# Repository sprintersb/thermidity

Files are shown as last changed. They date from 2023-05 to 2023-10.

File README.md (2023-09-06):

# Thermidity



AVR MCU based battery powered thermometer and hygrometer with e-ink display.  
Focus is on stable, accurate measurements and low power consumption. 
And of course on a nice, simple display.

The project is based on [avrink](https://github.com/gitdode/avrink) and uses the
following components:

* MCU AVR ATmega328P
* Thermistor NTC 100kΩ 0.1°C
* Humidity Sensor HIH-5030
* E-Ink display Adafruit Monochrome 2.13" 250x122
    * Driver SSD1680
    * SRAM 23K640
    * SD Card Reader (not used)
 
Thanks to https://github.com/sprintersb for helping me to improve the code and making it more efficient!



## Accuracy

AD conversion is done with 16x oversampling, yielding 12-bit virtual resolution 
with the 10-bit ADC, provided the signal contains some noise.

Each time measurements were taken, a moving average is updated which is used to 
calculate and display temperature, humidity and battery voltage.

A precision thermistor and precision low-voltage humidity sensor are used:

| Component  | Accuracy |
|---|---:|
| Thermistor |  ¹±0.1°C |
| HIH-5030 | ±3%RH |

¹Series resistor 0.1% tolerance

## Power Consumption

Estimated average power consumption is about 90µA when measuring every 32 
seconds and updating the display once in about 5 minutes, hopefully giving an
operating time of at least 12 months with 3 AAA batteries (1100 mAh, 6% 
self-discharge). 

The consumption of each component at 3.8V and 22°C is about:

| Component  | Data Sheet | Measured |
|---|---:|---:|
| ATmega328P | ¹4.2µA | 4.5µA |
| Thermistor | N/A | 24µA |
| HIH-5030 | ²200µA | 211µA |
| V-Divider  | N/A | 2µA |
| Display | ³N/A | 14µA |

¹VCC = 3V, power-down sleep mode  
²VCC = 3.3V  
³Display in deep sleep mode + SRAM + SD Card Reader + Bus Transceiver  

Between taking measurements, the MCU is set to power-down sleep mode with the
watchdog used as wake-up source. Additionally, the thermistor and humidity 
sensor are powered off and between display updates, the display is set to deep 
sleep mode. Power consumption (measured) then is about 19µA at 3.8V for MCU 
and display.  

When measuring temperature, humidity and battery voltage in ADC noise reduction 
mode, consumption seems to be somewhere around 2mA for 6ms, plus a brief 
additional MCU awake period for updating the moving average with measured 
values. Before measuring, the sensors are powered on and given 100ms to settle, 
consuming about 240µA.

When updating the display, consumption is at around 6mA for about 3 seconds. 
Before that, the MCU has to calculate and format the average measurements and 
buffer the frame in SRAM.

The display is updated in fast update mode, taking 1.5s instead of 3s for full 
update mode, saving a considerable amount of power. To avoid ghosting effects, 
every 10th update is a full update.

When no measurement has changed, the display is not updated at all to extend its 
lifetime and to save more power.

Below the cutoff voltage of 3.0V, the watchdog is disabled to stop measuring and
updating the display, to at least delay total discharge of the batteries.
Consumption of the MCU then is at about 1µA and 19µA of the display.

The clock of unused modules TWI, all three timers and USART is switched off to 
reduce power consumption.

Disabling the ADC between measurements and the SPI between display updates both 
contributes to a significant reduction of power consumption. With an enabled SPI, 
consumption of the display including its peripheral is extremely unstable and 
varies between some tens of microamps and several milliamps. When driving the 
enable pin of the display low, consumption is stable at about 60µA. When not 
driving the enable pin low and disabling SPI (driving SCK pin low) consumption 
is at about 14µA.

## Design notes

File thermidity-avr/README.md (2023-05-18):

# Thermidity



AVR MCU based battery powered thermometer and hygrometer with e-ink display 
(work in progress). 

The project is based on [avrink](https://github.com/gitdode/avrink) and uses the
following components:

* MCU AVR ATmega328P
* Voltage Reference MCP1501 3.000V
* Temperature Sensor TMP36
* Humidity Sensor HIH-5030
* E-Ink display Adafruit Monochrome 2.13" 250x122
    * Driver SSD1680
    * SRAM 23K640
    * SD Card Reader (not used) 



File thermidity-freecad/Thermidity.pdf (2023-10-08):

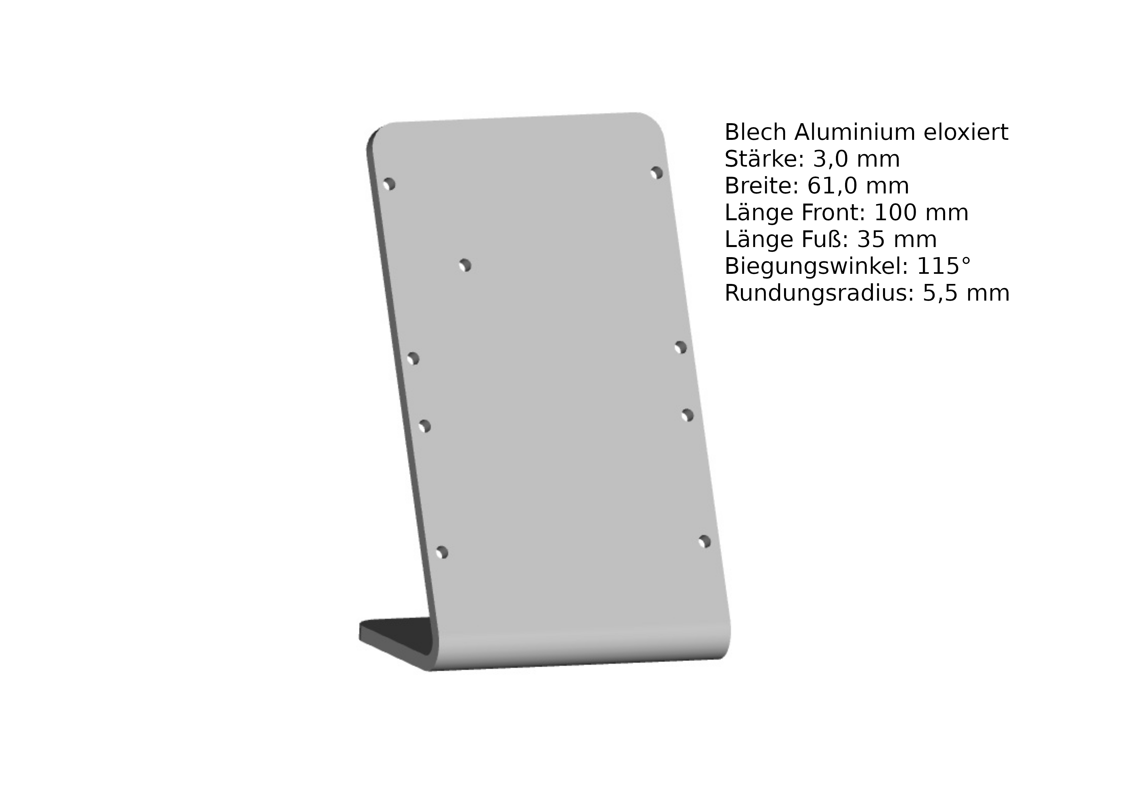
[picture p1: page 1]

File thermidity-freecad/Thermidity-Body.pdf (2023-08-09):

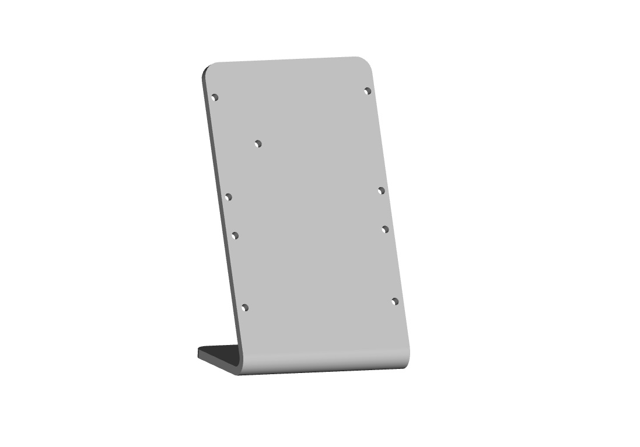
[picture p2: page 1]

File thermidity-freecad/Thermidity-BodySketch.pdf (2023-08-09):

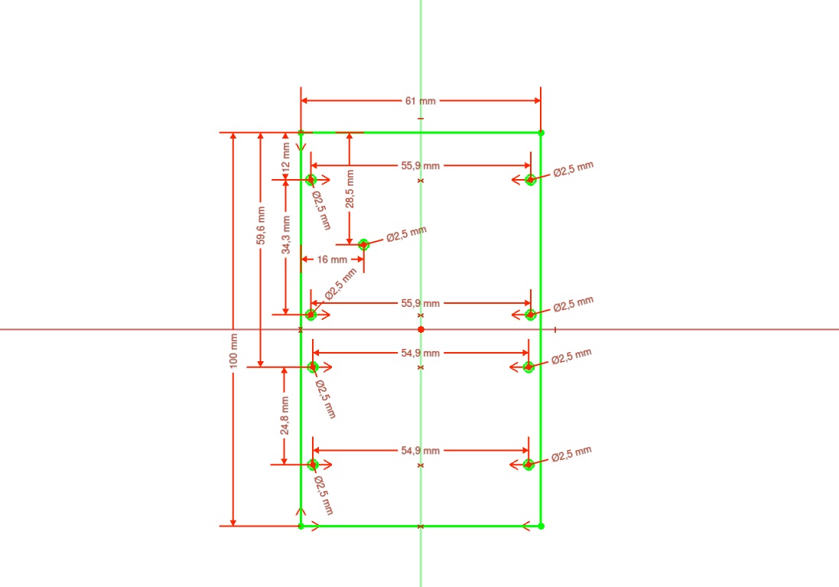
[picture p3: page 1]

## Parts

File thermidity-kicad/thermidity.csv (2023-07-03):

Source: | /home/dode/dev/thermidity/thermidity-kicad/thermidity.kicad_sch
Date: | Sa 01 Jul 2023 17:02:00 CEST
Tool: | Eeschema 6.0.11+dfsg-1
Generator: | /usr/share/kicad/plugins/bom_csv_grouped_by_value.py
Component Count: | 14
Individual Components:
Item | Qty | Reference(s) | Value | LibPart | Footprint | Datasheet | AVAILABILITY | MF | MP | PACKAGE | PRICE
 |  | C1 | 100nF | Device:C | Capacitor_SMD:C_1206_3216Metric_Pad1.33x1.80mm_HandSolder | ~
 |  | C2 | 1nF | Device:C | Capacitor_SMD:C_1206_3216Metric_Pad1.33x1.80mm_HandSolder | ~
 |  | C3 | 100nF | Device:C | Capacitor_SMD:C_1206_3216Metric_Pad1.33x1.80mm_HandSolder | ~
 |  | J1 | Battery | Connector_Generic:Conn_01x02 | Connector_JST:JST_PH_S2B-PH-K_1x02_P2.00mm_Horizontal | ~
 |  | J2 | Display | Connector:Conn_01x13_Female | Connector_PinSocket_2.54mm:PinSocket_1x13_P2.54mm_Vertical | ~
 |  | J3 | ISP | Connector:Conn_01x06_Female | Connector_PinSocket_2.54mm:PinSocket_1x06_P2.54mm_Vertical | ~
 |  | L1 | 10uH | Device:L | Inductor_SMD:L_1210_3225Metric_Pad1.42x2.65mm_HandSolder | ~
 |  | R1 | 300K | Device:R | Resistor_SMD:R_0805_2012Metric_Pad1.20x1.40mm_HandSolder | ~
 |  | R2 | 1.2M | Device:R | Resistor_SMD:R_0805_2012Metric_Pad1.20x1.40mm_HandSolder | ~
 |  | R3 | 100k 0.1% | Device:R | Resistor_SMD:R_0805_2012Metric_Pad1.20x1.40mm_HandSolder | ~
 |  | R4 | 65k | Device:R | Resistor_SMD:R_0805_2012Metric_Pad1.20x1.40mm_HandSolder | ~
 |  | TH1 | NTC 100k 0.1°C | Device:Thermistor_NTC | Resistor_SMD:R_0805_2012Metric_Pad1.20x1.40mm_HandSolder | ~
 |  | U1 | ATmega328P | MCU_Microchip_ATmega:ATmega328P-A | Package_QFP:TQFP-32_7x7mm_P0.8mm | http://ww1.microchip.com/downloads/en/DeviceDoc/ATmega328_P%20AVR%20MCU%20with%20picoPower%20Technology%20Data%20Sheet%2040001984A.pdf
 |  | U2 | HIH-5030 | HIH-5030-001:HIH-5030-001 | HIH-5030-001:HONEYWELL_HIH-5030-001 |  | Good | Honeywell | HIH-5030-001 | None | $6.78 USD
Collated Components:
Item | Qty | Reference(s) | Value | LibPart | Footprint | Datasheet | AVAILABILITY | MF | MP | PACKAGE | PRICE
1 | 2 | C1, C3 | 100nF | Device:C | Capacitor_SMD:C_1206_3216Metric_Pad1.33x1.80mm_HandSolder | ~
2 | 1 | C2 | 1nF | Device:C | Capacitor_SMD:C_1206_3216Metric_Pad1.33x1.80mm_HandSolder | ~
3 | 1 | J1 | Battery | Connector_Generic:Conn_01x02 | Connector_JST:JST_PH_S2B-PH-K_1x02_P2.00mm_Horizontal | ~
4 | 1 | J2 | Display | Connector:Conn_01x13_Female | Connector_PinSocket_2.54mm:PinSocket_1x13_P2.54mm_Vertical | ~
5 | 1 | J3 | ISP | Connector:Conn_01x06_Female | Connector_PinSocket_2.54mm:PinSocket_1x06_P2.54mm_Vertical | ~
6 | 1 | L1 | 10uH | Device:L | Inductor_SMD:L_1210_3225Metric_Pad1.42x2.65mm_HandSolder | ~
7 | 1 | R1 | 300K | Device:R | Resistor_SMD:R_0805_2012Metric_Pad1.20x1.40mm_HandSolder | ~
8 | 1 | R2 | 1.2M | Device:R | Resistor_SMD:R_0805_2012Metric_Pad1.20x1.40mm_HandSolder | ~
9 | 1 | R3 | 100k 0.1% | Device:R | Resistor_SMD:R_0805_2012Metric_Pad1.20x1.40mm_HandSolder | ~
10 | 1 | R4 | 65k | Device:R | Resistor_SMD:R_0805_2012Metric_Pad1.20x1.40mm_HandSolder | ~
11 | 1 | TH1 | NTC 100k 0.1°C | Device:Thermistor_NTC | Resistor_SMD:R_0805_2012Metric_Pad1.20x1.40mm_HandSolder | ~
12 | 1 | U1 | ATmega328P | MCU_Microchip_ATmega:ATmega328P-A | Package_QFP:TQFP-32_7x7mm_P0.8mm | http://ww1.microchip.com/downloads/en/DeviceDoc/ATmega328_P%20AVR%20MCU%20with%20picoPower%20Technology%20Data%20Sheet%2040001984A.pdf
13 | 1 | U2 | HIH-5030 | HIH-5030-001:HIH-5030-001 | HIH-5030-001:HONEYWELL_HIH-5030-001 |  | Good | Honeywell | HIH-5030-001 | None | $6.78 USD

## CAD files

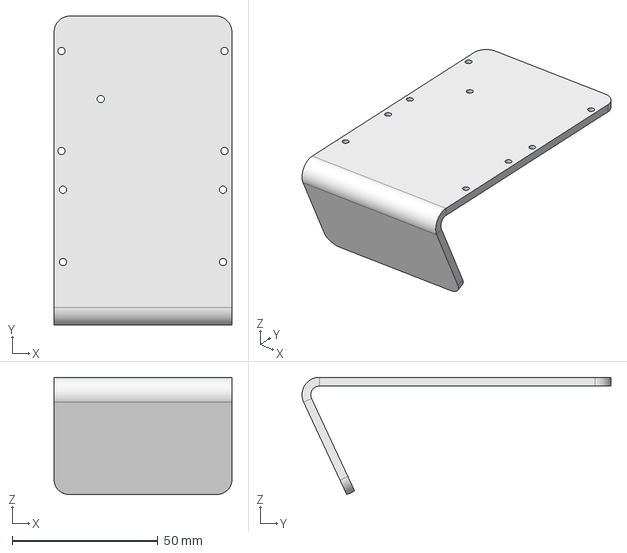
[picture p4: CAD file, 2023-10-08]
thermidity-freecad/Thermidity-Body.step
61.0 x 106.0 x 40.3 mm

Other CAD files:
thermidity-freecad/Thermidity.FCStd
thermidity-freecad/Thermidity-BodySketch.step

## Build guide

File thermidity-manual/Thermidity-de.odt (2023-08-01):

Thermidity

Batteriebetriebenes Thermometer und Hygrometer

# Beschreibung

Thermidity ist ein einfaches Thermometer und Hygrometer bei dessen Entwicklung besonderer Wert auf ein gut ablesbares Display, hohe Messgenauigkeit, geringen Stromverbrauch und die Verwendung möglichst weniger aber dafür hochwertiger Bauteile gelegt wurde.

Die Software kann aktualisiert werden, wodurch zukünftige Anpassungen und Verbesserungen möglich sind.

Alle verwendeten Bauteile sind RoHS konform.
Bei der Herstellung dieses Thermometers wurde bleifreies Lot verwendet.

Made with 💜 by Dode

# Komponenten

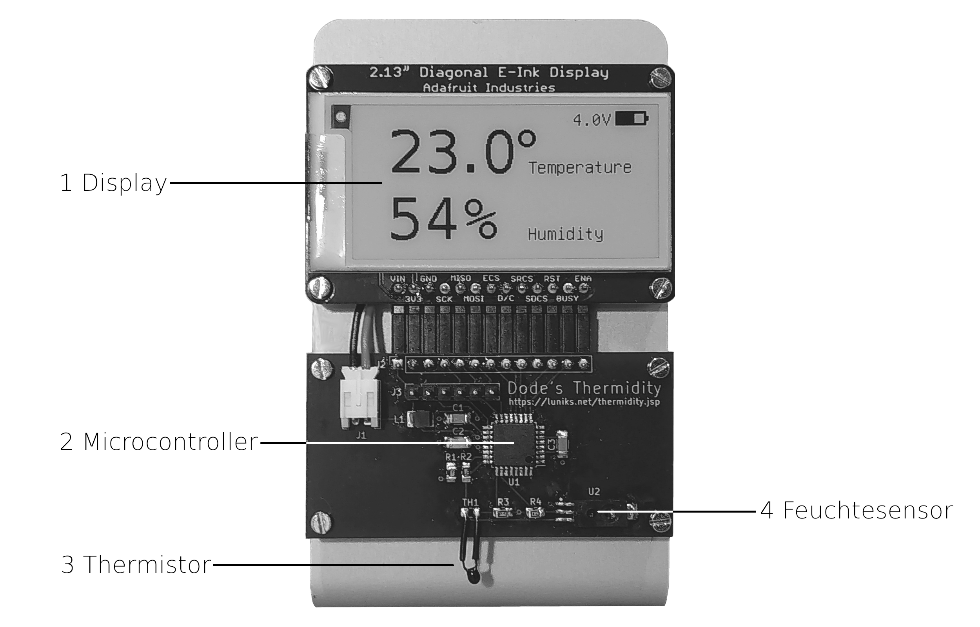
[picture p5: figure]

1. Display Adafruit Monochrome 2.13" 250x122
2. Microcontroller Atmel/Microchip AVR ATmega328P
3. Thermistor (Temperaturfühler) NTC 100kΩ 0.1°C
4. Feuchtesensor Honeywell HIH-5030

# Inbetriebnahme

⚠
Beim Einlegen der Batterien darauf achten, dass kein Druck auf das Display und die übrigen Bauteile ausgeübt wird und der Temperaturfühler nicht beschädigt oder verbogen wird.

1. Deckel des Batteriefachs durch leichten Druck unten auf die Riffelung und gleichzeitiges Schieben nach oben entfernen
2. Batterien einlegen, dabei auf richtige Polung achten
3. Deckel auf das Fach legen und durch leichten Druck auf die Riffelung und gleichzeitiges Schieben nach unten schließen
4. Nach ca. 1,5 Sekunden wird die aktuelle Temperatur und Luftfeuchtigkeit angezeigt
5. Das Thermometer an einem Ort aufstellen an dem es nicht Nässe oder über längere Zeit direkter Sonneneinstrahlung ausgesetzt ist

⚠
Beim Aufstellen des Thermometers bitte darauf achten, dass die Oberfläche von empfindlichen Möbeln nicht von den Kanten des Aluminiumrahmens verkratzt wird.

# Technische Daten

Parameter | Wert
Betriebsspannung | 3 – 5V
Betriebstemperatur | 0 – 50°C
Durchschnittlicher Stromverbrauch | ca. 90µA
Betriebsdauer mit Alkali-Mangan Batterien AAA/Micro¹ | ca. 12 Monate
Genauigkeit Temperaturmessung | ±0,1°C
Genauigkeit relative Luftfeuchtigkeitsmessung | ±3%
Messbereich Temperatur² | -40 – +99,9°C
Messbereich Luftfeuchtigkeit | 0 – 99%
Messintervall | ca. 32 Sek.
Aktualisierungsintervall | ca. 5 Min.
Displayauflösung | 255 x 122 Pixel
Prozessortakt | 8 MHz

¹ Bei Verwendung von Akkus kann die Betriebsdauer wegen der geringeren Zellspannung und ggf. geringeren Kapazität sowie der höheren Selbstentladung kürzer ausfallen.

² Einschränkung der Betriebstemperatur auf 0 – 50°C ist durch das Display bedingt. Die Aufbewahrungstemperatur beträgt -25 – +70°C.

# Technische Details

Die Messung von Temperatur und Luftfeuchtigkeit erfolgt ca. alle 32 Sekunden ratiometrisch über einen 10-bit Analog-Digital Wandler. Durch 16-faches Oversampling wird eine virtuelle Auflösung von 12 Bit erreicht.

Mit jeder Messung wird ein gleitender Mittelwert aktualisiert, aus dem ca. alle 5 Minuten der Messwert berechnet und mit dem Ergebnis die Anzeige aktualisiert wird.

Für geringeren Stromverbrauch wird das Display im Schnellmodus aktualisiert. Jede zehnte Aktualisierung wird jedoch ein vollständiges Update durchgeführt, um ein bei niedrigen Temperaturen eventuell auftretendes „Geisterbild“ zu beseitigen.
Hat sich seit der letzten Aktualisierung kein Messwert geändert, wird die Anzeige nicht unnötig aktualisiert, was neben einer zusätzlichen Verringerung des Stromverbrauchs die Lebensdauer des Displays verlängert.

Um den Stromverbrauch weiter zu reduzieren, werden die Sensoren zwischen den Messungen abgeschaltet. Der Prozessor wird zudem in einen Schlafmodus versetzt und in regelmäßigen Abständen von einem Wachhund aufgeweckt.

Sinkt die Batteriespannung unter das Minimum von 3V, wird der Wachhund in Ruhestand geschickt. Der Prozessor wird dann nicht mehr aufgeweckt und führt daher keine weiteren Messungen und Aktualisierungen der Anzeige durch. Mit der dabei erreichten Verringerung des Stromverbrauchs wird eine schädliche Tiefentladung von Akkus erheblich hinausgezögert.

⚠
Da keine vollständige Abschaltung erfolgt und ein Ruhestrom von ca. 20µA verbleibt, sollten leere Batterien und Akkus bald ersetzt bzw. wieder aufgeladen werden.

# Vergleich mit anderen Thermometern und Hygrometern

Beim direkten Vergleich der Messwerte dieses Thermometers mit z.B. handelsüblichen „Wetterstationen“ kann es zu Abweichungen kommen. Die Ursachen dafür können sein:

- Das Vergleichsgerät ist ungenau: Die Genauigkeit von Wetterstationen beträgt oft nur ±0,5 – 1°C Temperatur und z.T. mehr als ±5% relative Luftfeuchtigkeit. Dabei sei bemerkt dass Feuchtesensoren mit hoher Genauigkeit, wie in diesem Gerät verwendet, sehr teuer sind.
- Unterschiedliche Empfindlichkeit: Da sich bei diesem Thermometer die Sensoren nicht in einem Gehäuse befinden, reagiert es möglicherweise empfindlicher auf z.B. Zugluft als andere Geräte.
- Unterschiedliches Aktualisierungsintervall der Anzeige: Bei diesem Thermometer wird die Anzeige nur ca. alle 5 Minuten aktualisiert.

# Problembehebung

Problem | Ursache | Lösung
Anzeige wird nicht aktualisiert | Batterien leer (<= 3.0V) | Batterien ersetzen/Akkus aufladen
Anzeige ist grau und verwaschen | Batterien leer (<= 3.0V) | Batterien ersetzen/Akkus aufladen
Angezeigte Luftfeuchtigkeit beträgt +99% | Kondensation durch spontanen Temperatur-anstieg | Gerät akklimatisieren lassen
Gerät ist nass geworden | | Batterien entfernen und Gerät trocknen lassen
Gerät ist eingefroren | | Batterien entfernen und Gerät auftauen und trocknen lassen

# Sicherheitshinweise

Das Thermometer ist nicht spritzwassergeschützt und eignet sich daher nicht für den Betrieb in der Nähe von z.B. Waschbecken.

Das Thermometer nicht dauerhaft direkter Sonneneinstrahlung aussetzen. Die Funktion des Displays kann dadurch bleibend beeinträchtigt werden.

⚠
Das Display besteht aus Glas. Vorsicht Verletzungsgefahr bei Beschädigungen.
Sollte das Display zerbrechen, Kontakt mit ggf. austretender Flüssigkeit vermeiden. Bei Kontakt mit Wasser und Seife abwaschen.

# Referenzen

Email: torsten.roemer@luniks.net

Webseite: https://luniks.net/thermidity.jsp

Quellcode: https://github.com/gitdode/thermidity

Thermidity 2023-07-31 – Seite 8

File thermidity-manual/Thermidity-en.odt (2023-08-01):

Thermidity

Battery powered Thermometer and Hygrometer

# Description

Thermidity is a simple thermometer and hygrometer. During its development, particular effort was made for good readability of the display, high accuracy, low power consumption and using few but high-quality components.

The ability to update the software allows for future adjustments and improvements.

All components used are RoHS compliant.
Lead-free solder was used in the production of this thermometer.

Made with 💜 by Dode

# Components


1. Display Adafruit Monochrome 2.13" 250x122
2. Microcontroller Atmel/Microchip AVR ATmega328P
3. Thermistor (Temperature Sensor) NTC 100kΩ 0.1°C
4. Humidity Sensor Honeywell HIH-5030

# Usage

⚠
Make sure not to apply pressure on the display and the other components and not to damage or bend the temperature sensor when inserting the batteries.

1. Open the battery case by slightly pressing on the markings at the bottom and sliding the cover upwards
2. Insert the batteries, observe the polarity
3. Place the cover on the case and close it by slightly pressing on the markings and sliding it downwards
4. After about 1.5 seconds the current temperature and humidity is displayed
5. Place the thermometer at a location where it is not exposed to moisture or direct sunlight for longer periods of time

⚠
When placing the thermometer, please take care not to scratch the surface of delicate furniture with the edges of the aluminium frame.

# Technical Specification

Parameter | Value
Operating Voltage | 3 – 5V
Operating Temperature | 0 – 50°C
Average Power Supply Current | about 90µA
Operating Time with alkaline battery AAA/Micro¹ | about 12 months
Accuracy Temperature Measurement | ±0.1°C
Accuracy relative Humidity Measurement | ±3%
Measuring Range Temperature² | -40 – +99.9°C
Measuring Range Humidity | 0 – 99%
Measuring Interval | about 32 sec.
Update Interval | about 5 min.
Display Resolution | 255 x 122 Pixel
CPU Clock | 8 MHz

¹ Operating time can be shorter when using rechargeable batteries because of the lower voltage and possibly lower capacity, and the higher self-discharge.

² Operation temperature is limited to 0 – 50°C by the display. Storage temperature is -25 – +70°C.

# Technical Details

Measurement of temperature and humidity is done about every 32 seconds ratiometrically with a 10-bit analogue digital converter and 16-times oversampling, yielding a virtual resolution of 12 Bit.

A moving average is updated with each measurement. About every 5 minutes, the measurement values are calculated from that average, and the display is updated with the result.

To reduce power consumption, the display is updated in fast mode. Each 10th update however, a full update is done to remove ghosting that can possibly occur at low temperatures.
If no measurement value changed since last update, the display is not updated unnecessarily to further reduce power consumption and extend the lifetime of the display.

For additional reduction of power consumption, the sensors are switched off between measurements, and the CPU is put to sleep mode and woken up by a watchdog at a regular interval.

When the battery voltage goes below a minimum of 3V, the watchdog is retired so the CPU is not woken up any more and thus does not perform further measurements and display updates. With the achieved reduction of power consumption, a harmful total discharge of rechargeable batteries is delayed significantly.

⚠
Because the device is not powered down completely and an idle current of about 20µA remains, empty (rechargeable) batteries should soon be replaced or recharged, respectively.

# Comparison with other Thermometers and Hygrometers

Direct comparison of the measurement values of this thermometers with for example commercially available “Weather Stations” can reveal a certain deviation. Causes for this can be:

- The device used for comparison is inaccurate: The accuracy of weather stations commonly is only ±0.5 – 1°C temperature and sometimes more than ±5% relative Humidity. It should be noted that humidity sensors with high accuracy, as used in this device, are very expensive.
- Different sensitivity: The sensors of this thermometer are not inside a case, so it is possibly more sensitive to for example draught as other devices.
- Different display update interval: This thermometer updates the display only about every 5 minutes.

# Troubleshooting

Problem | Cause | Solution
Display is not updated | Batteries weak (<= 3.0V) | Replace/recharge batteries
Display is greyish and blurry | Batteries weak (<= 3.0V) | Replace/recharge batteries
Humidity displayed is +99% | Condensation caused by spontaneous rise of temperature | Let the device acclimate itself
Device is wet | | Remove batteries and let the device dry
Device is frozen | | Remove batteries and let the device thaw and dry

# Safety Notes

The thermometer is not splash proof and therefore not suitable to be operated close to for example a bathroom sink.

Do not expose the thermometer to direct sunlight for long periods of time as this can cause degraded performance of the display.

⚠
The display is made of glass. Attention risk of injury when damaged.
Should the display break, avoid contact with possibly leaking liquid. In case of contact, wash with water and soap.

# References

Email: torsten.roemer@luniks.net

Website: https://luniks.net/thermidity.jsp

Source code: https://github.com/gitdode/thermidity

Thermidity 2023-07-31 – Page 8

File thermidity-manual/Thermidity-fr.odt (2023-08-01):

Thermidity

Thermomètre et hygromètre à piles

# Description

Thermidity est un simple thermomètre et hygromètre. Au cours de son développement, un effort particulier a été fait pour une bonne lisibilité de l'affichage, une grande précision, une faible consommation d'énergie et l'utilisation de composants peu nombreux mais de haute qualité.

La possibilité de mettre à jour le logiciel permet de futurs ajustements et améliorations.

Tous les composants utilisés sont conformes RoHS.
Une soudure sans plomb a été utilisée dans la fabrication de ce thermomètre.

Made with 💜 by Dode

La traduction de l'anglais a été faite avec l'aide de Google Translate.

# Composants


1. Écran Adafruit Monochrome 2.13" 250x122
2. Microcontrôleur Atmel/Microchip AVR ATmega328P
3. Thermistance (capteur de température) NTC 100kΩ 0,1°C
4. Capteur d'humidité Honeywell HIH-5030

# Usage

⚠
Assurez-vous de ne pas appliquer de pression sur l'écran et les autres composants et de ne pas endommager ou plier le capteur de température lors de l'insertion des piles.

1. Ouvrez le boîtier de piles en appuyant légèrement sur les marques en bas et en faisant glisser le couvercle vers le haut
2. Insérez les piles, respectez la polarité
3. Placez le couvercle sur le boîtier et fermez-le en appuyant légèrement sur les marques et en le faisant glisser vers le bas
4. Après environ 1,5 seconde, la température et l'humidité actuelles s'affichent
5. Placez le thermomètre à un endroit où il n'est pas exposé à l'humidité ou à la lumière directe du soleil pendant de longues périodes

⚠
Lorsque vous placez le thermomètre, veillez à ne pas rayer la surface des meubles délicats avec les bords du cadre en aluminium.

# Spécifications techniques

Paramètre | Valeur
Voltage de fonctionnement | 3 – 5V
Température de fonctionnement | 0 – 50°C
Courant d'alimentation moyen | env. 90µA
Autonomie avec pile alcaline AAA/Micro¹ | env. 12 mois
Précision de mesure de température | ±0,1°C
Précision de mesure de humidité relative | ±3%
Plage de mesure de température² | -40 – +99,9°C
Plage de mesure de humidité | 0 – 99%
Intervalle de mesure | env. 32 sec.
Intervalle de mise à jour | env. 5 min.
Résolution d'affichage | 255 x 122 pixels
Horloge du processeur | 8 MHz

¹ Le temps de fonctionnement peut être plus court lors de l'utilisation de piles rechargeables en raison de la voltage plus faible et éventuellement de la capacité inférieure, ainsi que de l'autodécharge plus élevée.

² La température de fonctionnement est limitée à 0 – 50°C par l'affichage. La température de stockage est de -25 à +70°C.

# Détails techniques

La mesure de la température et de l'humidité est effectuée environ toutes les 32 secondes de manière ratiométrique avec un convertisseur numérique analogique 10 bits et un suréchantillonnage 16 fois, ce qui donne une résolution virtuelle de 12 bits.

Une moyenne mobile est mise à jour à chaque mesure. Toutes les 5 minutes environ, les valeurs de mesure sont calculées à partir de cette moyenne et l'affichage est mis à jour avec le résultat.

Pour réduire la consommation d'énergie, l'affichage est mis à jour en mode rapide. Cependant, chaque 10e mise à jour, une mise à jour complète est effectuée pour supprimer les images fantômes qui peuvent éventuellement se produire à basse température.

Si aucune valeur de mesure n'a changé depuis la dernière mise à jour, l'affichage n'est pas mis à jour inutilement pour réduire la consommation d'énergie et prolonger la durée de vie de l'affichage.

Pour une réduction supplémentaire de la consommation d'énergie, les capteurs sont éteints entre les mesures et le processeur est mis en mode veille et réveillé par un chien de garde à intervalles réguliers.

Lorsque la voltage des piles descend en dessous d'un minimum de 3V, le chien de garde est envoyé à la retraite afin que le CPU ne soit plus réveillé et n'effectue donc plus de mesures et de mises à jour d'affichage. Avec la réduction obtenue de la consommation d'énergie, une décharge totale nocive des piles rechargeables est retardée de manière significative.

⚠
Parce que l'appareil n'est pas complètement éteint et qu'il reste un courant de repos d'environ 20µA, les piles (rechargeables) vides doivent bientôt être remplacées ou rechargées.

# Comparaison avec d'autres Thermomètres et Hygromètres

Une comparaison directe des valeurs de mesure de ces thermomètres avec, par exemple, des «stations météorologiques» disponibles dans le commerce peut révéler un certain écart. Les causes peuvent être :

- L'appareil utilisé pour la comparaison est imprécis : La précision des stations météo n'est généralement que de ±0,5 – 1°C de température et parfois plus de ±5% d'humidité relative. Il convient de noter que les capteurs d'humidité de grande précision, tels qu'utilisés dans cet appareil, sont très coûteux.
- Sensibilité différente : les capteurs de ce thermomètre ne sont pas à l'intérieur d'un boîtier, il est donc peut-être plus sensible, par exemple, aux courants d'air que d'autres appareils.
- Intervalle de mise à jour de l'affichage différent : Ce thermomètre ne met à jour l'affichage qu'environ toutes les 5 minutes.

# Dépannage

Problème | Cause | Solution
L'affichage n'est pas mis à jour | Piles faibles (<= 3.0V) | Remplacer/recharger les piles
L'affichage est grisâtre et flou | Piles faibles (<= 3.0V) | Remplacer/recharger les piles
L'humidité affichée est de +99% | Condensation causée par une élévation spontanée de la température | Laissez l'appareil s'acclimater
L'appareil est mouillé | | Retirez les piles et laissez sécher l'appareil
L'appareil est gelé | | Retirez les piles et laissez dégeler et sécher l'appareil

# Consignes de sécurité

Le thermomètre n'est pas étanche aux éclaboussures et ne peut donc pas être utilisé à proximité, par exemple, d'un lavabo.

N'exposez pas le thermomètre à la lumière directe du soleil pendant de longues périodes car cela peut entraîner une dégradation des performances de l'affichage.

⚠
L'écran est en verre. Attention risque de blessure en cas d'endommagement. En cas de bris de l'affichage, évitez tout contact avec un liquide susceptible de fuir. En cas de contact, laver avec de l'eau et du savon.

# Références

Courriel : torsten.roemer@luniks.net
Site Web : https://luniks.net/thermidity.jsp
Code source : https://github.com/gitdode/thermidity

Thermidity 2023-07-31 – Page 8

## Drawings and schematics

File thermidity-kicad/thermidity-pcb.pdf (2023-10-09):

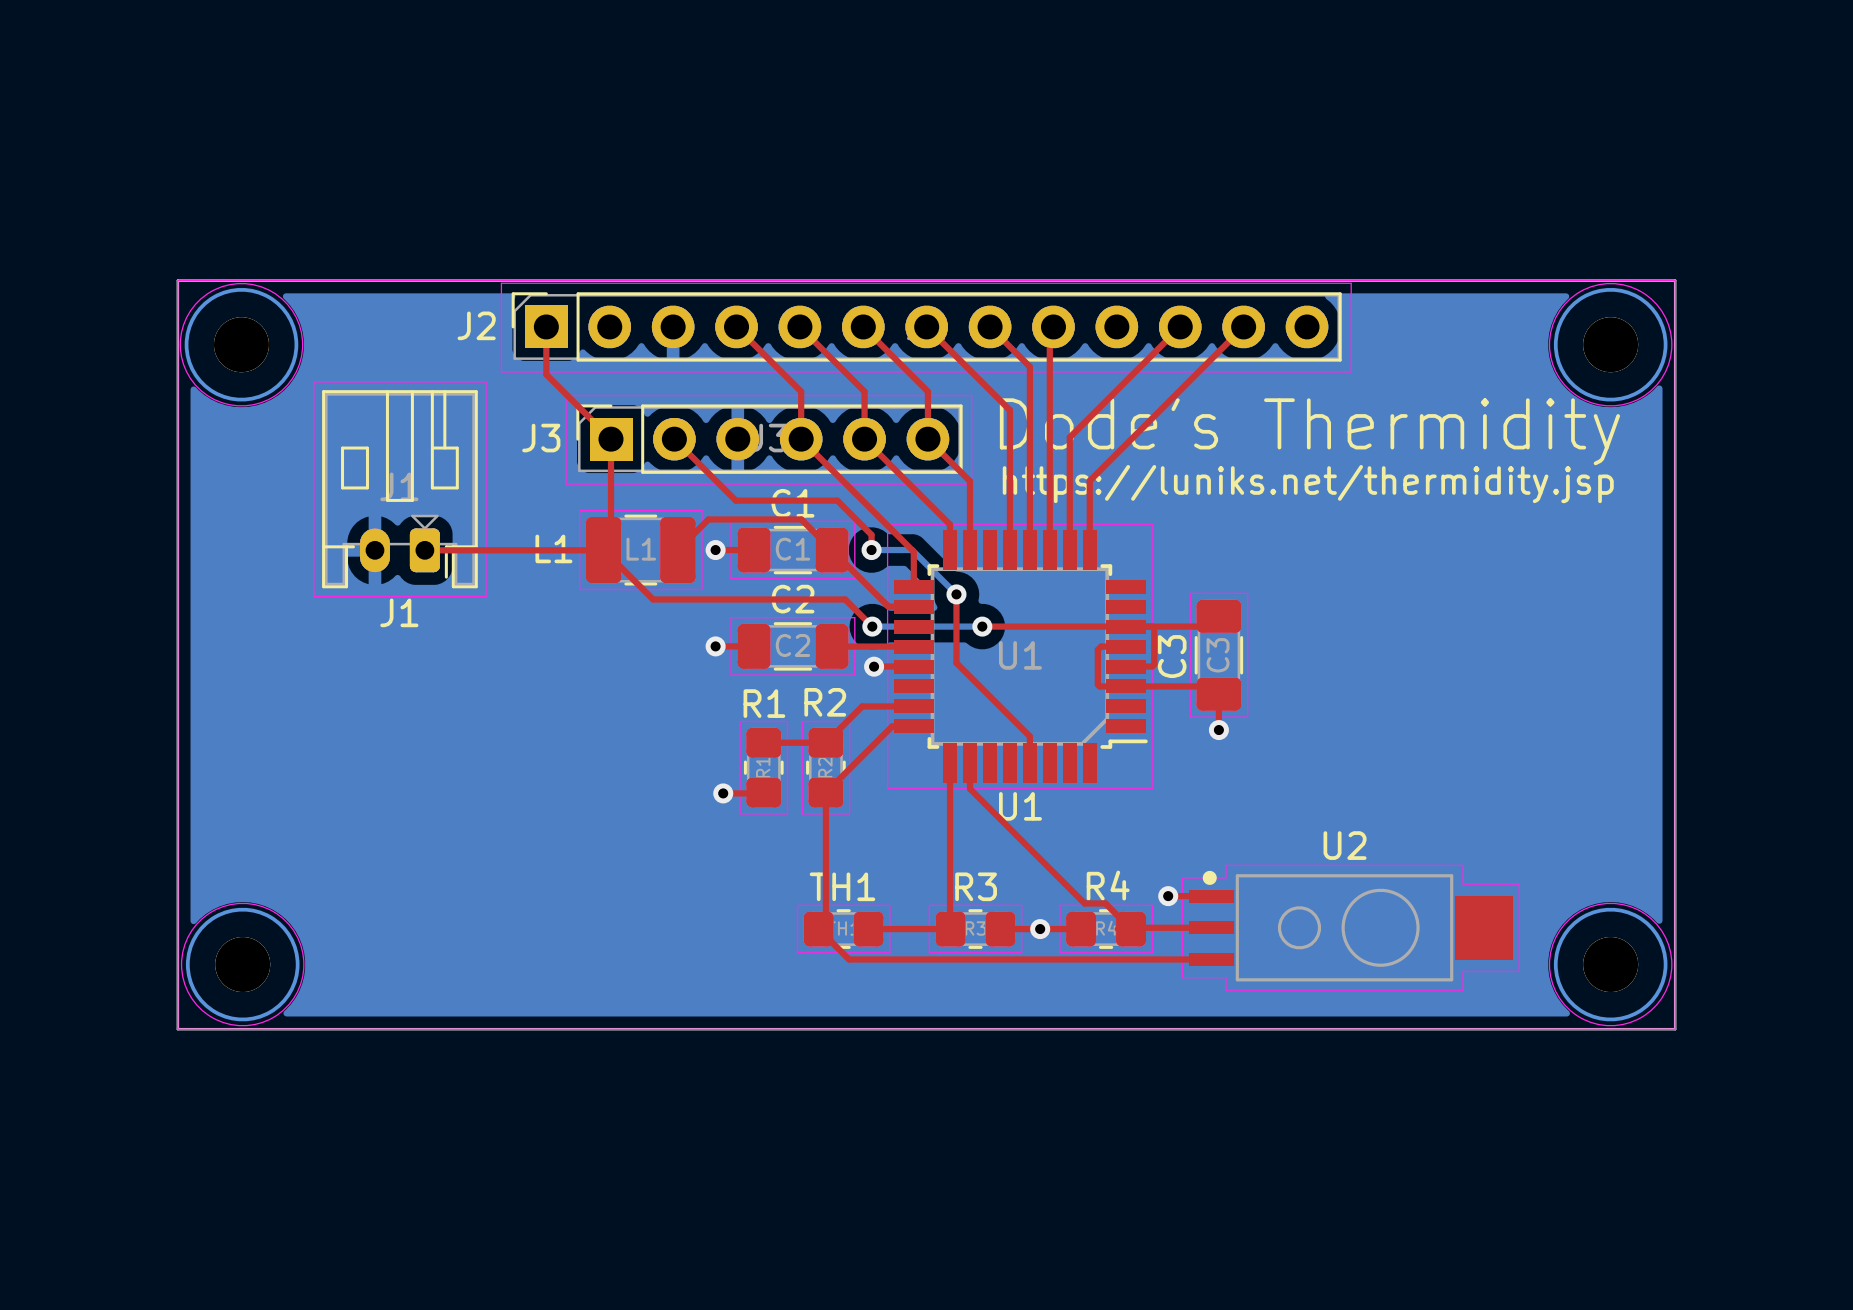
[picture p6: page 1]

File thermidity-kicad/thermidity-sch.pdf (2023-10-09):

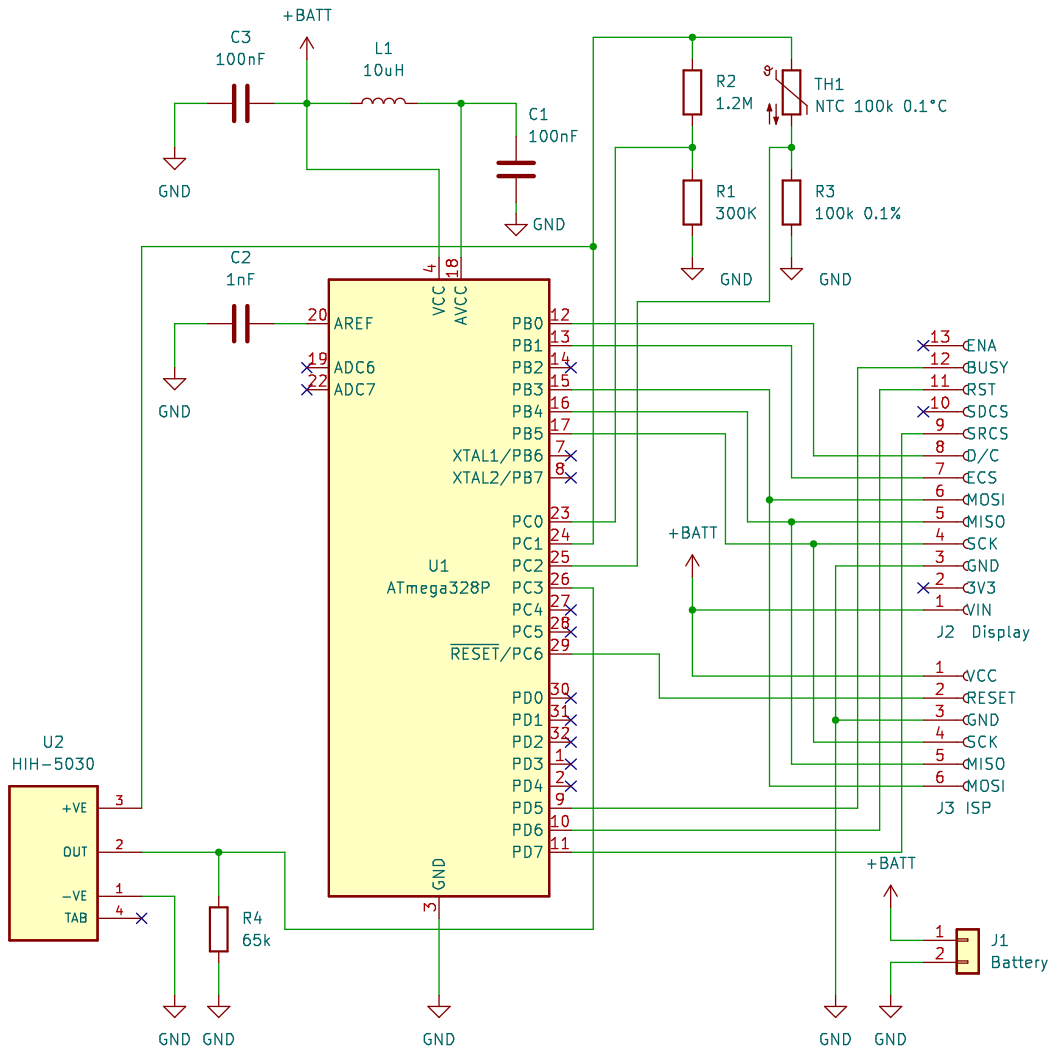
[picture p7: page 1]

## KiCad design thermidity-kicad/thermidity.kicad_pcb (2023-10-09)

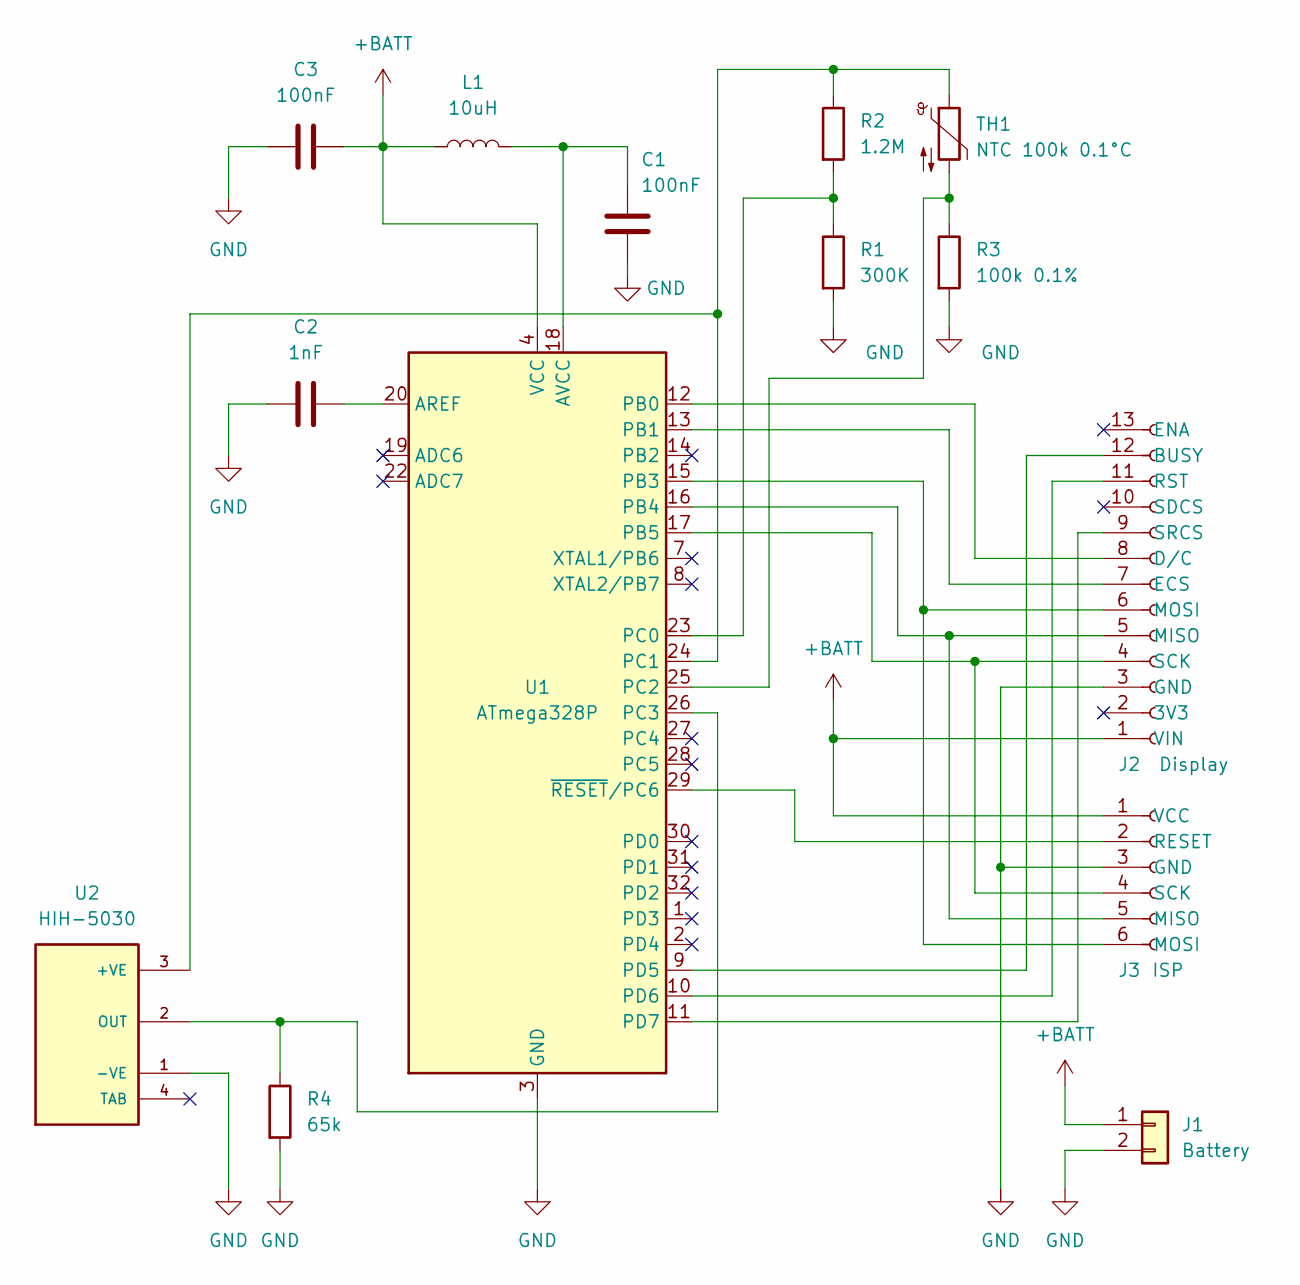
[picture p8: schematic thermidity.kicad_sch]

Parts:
C1, C3: 100nF; C_1206_3216Metric_Pad1.33x1.80mm_HandSolder
C2: 1nF; C_1206_3216Metric_Pad1.33x1.80mm_HandSolder
J1: Battery; JST_PH_S2B-PH-K_1x02_P2.00mm_Horizontal
J2: Display; PinSocket_1x13_P2.54mm_Vertical
J3: ISP; PinSocket_1x06_P2.54mm_Vertical
L1: 10uH; L_1210_3225Metric_Pad1.42x2.65mm_HandSolder
R1: 300K; R_0805_2012Metric_Pad1.20x1.40mm_HandSolder
R2: 1.2M; R_0805_2012Metric_Pad1.20x1.40mm_HandSolder
R3: 100k 0.1%; R_0805_2012Metric_Pad1.20x1.40mm_HandSolder
R4: 65k; R_0805_2012Metric_Pad1.20x1.40mm_HandSolder
TH1: NTC 100k 0.1°C; R_0805_2012Metric_Pad1.20x1.40mm_HandSolder
U1: ATmega328P; TQFP-32_7x7mm_P0.8mm
U2: HIH-5030; HONEYWELL_HIH-5030-001

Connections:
+BATT: C3.2, J1.1, J2.1 (VIN), J3.1 (VCC), L1.1, U1.4 (VCC), U1.6 (VCC)
GND: C1.1, C2.1, C3.1, J1.2, J2.3 (GND), J3.3 (GND), R1.2, R3.2, R4.2, U1.3 (GND), U1.5 (GND), U1.21 (GND), U2.1 (-VE)
unnamed: C1.2, L1.2, U1.18 (AVCC)
unnamed: C2.2, U1.20 (AREF)
unnamed: J2.4 (SCK), J3.4 (SCK), U1.17 (PB5)
unnamed: J2.5 (MISO), J3.5 (MISO), U1.16 (PB4)
unnamed: J2.6 (MOSI), J3.6 (MOSI), U1.15 (PB3)
unnamed: J2.7 (ECS), U1.13 (PB1)
unnamed: J2.8 (D/C), U1.12 (PB0)
unnamed: J2.9 (SRCS), U1.11 (PD7)
unnamed: J2.11 (RST), U1.10 (PD6)
unnamed: J2.12 (BUSY), U1.9 (PD5)
unnamed: J3.2 (RESET), U1.29 (~RESET/PC6)
unnamed: R1.1, R2.2, U1.23 (PC0)
unnamed: R2.1, TH1.1, U1.24 (PC1), U2.3 (+VE)
unnamed: R3.1, TH1.2, U1.25 (PC2)
unnamed: R4.1, U1.26 (PC3), U2.2 (OUT)

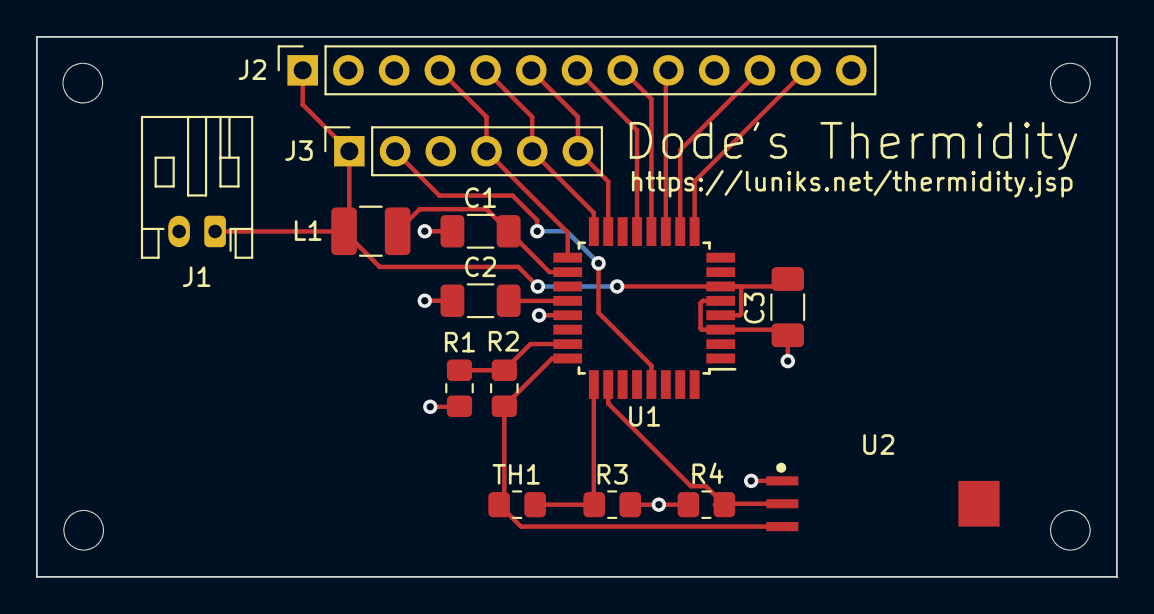
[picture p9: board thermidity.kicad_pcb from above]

Board: 2 copper layers, 60.0 x 30.0 mm, 18 parts (0 on the bottom side), 17 nets.

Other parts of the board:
H1, H2, H3, H4: M2; MountingHole_2.2mm_M2

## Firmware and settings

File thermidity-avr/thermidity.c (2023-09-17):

/*
 * thermidity.c
 *
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
 * AVR MCU based thermometer and hygrometer with e-ink display.
 *
 * Created on: 01.05.2023
 *     Author: torsten.roemer@luniks.net
 *
 */

#include <stdbool.h>
#include <stdlib.h>
#include <stdio.h>
#include <string.h>
#include <avr/io.h>
#include <avr/interrupt.h>
#include <avr/sleep.h>
#include <avr/wdt.h>
#include <util/delay.h>
#include <util/atomic.h>

#include "pins.h"
#include "meter.h"
#include "spi.h"
#include "sram.h"
#include "eink.h"
#include "display.h"
#include "utils.h"
#include "usart.h"

/* Measure and average temperature and relative humidity every ~32 seconds */
#define MEASURE_INTS    4 // should be a power of 2 to avoid division 
/* Display should not be updated more frequently than once every 180 seconds */
#define DISP_UPD_INTS   36
/* Number of fast updates until a full update is done to avoid ghosting */
#define DISP_MAX_FAST   9

/* 1 int = 8 seconds */
static volatile uint8_t ints = DISP_UPD_INTS;

static uint8_t updates = DISP_MAX_FAST + 1;

ISR(WDT_vect) {
    ints++;
}

EMPTY_INTERRUPT(ADC_vect);

/**
 * Sets up the pins.
 */
static void initPins(void) {
    // set sensor power pin as output pin
    DDR_SENS |= (1 << PIN_PWR);
    // drive sensor power pin low
    PORT_SENS &= ~(1 << PIN_PWR);

    // set MOSI and SCK as output pin
    DDR_SPI |= (1 << PIN_MOSI);
    DDR_SPI |= (1 << PIN_SCK);
    // pull SS (ensure master) and MISO high
    PORT_SPI |= (1 << PIN_SS);
    PORT_SPI |= (1 << PIN_MISO);

    // set SRAM CS pin as output pin
    DDR_SSPI |= (1 << PIN_SRCS);

    // set display CS, D/C and RST pin as output pin
    DDR_DSPI |= (1 << PIN_ECS);
    DDR_DSPI |= (1 << PIN_DC);
    DDR_DISP |= (1 << PIN_RST);

    // drive SPI and display output pins high
    PORT_SSPI |= (1 << PIN_SRCS);
    PORT_DSPI |= (1 << PIN_ECS);
    PORT_DSPI |= (1 << PIN_DC);
    PORT_DISP |= (1 << PIN_RST);

    // set display BUSY pin as input pin (default)
    DDR_DISP &= ~(1 << PIN_BUSY);

    // pull all unused pins high/set to defined level to reduce current
    // consumption when not in sleep mode
    PORTB |= (1 << PB6);
    PORTB |= (1 << PB7);
    PORTC |= (1 << PC4);
    PORTC |= (1 << PC5);
    PORTD |= (1 << PD0);
    PORTD |= (1 << PD1);
    PORTD |= (1 << PD2);
    PORTD |= (1 << PD3);
    PORTD |= (1 << PD4);
}

/**
 * Enables SPI master mode.
 */
static void initSPI(void) {
    SPCR |= (1 << SPR0);
    SPCR |= (1 << MSTR);
}

/**
 * Sets up the watchdog.
 */
static void initWatchdog(void) {
    cli();
    wdt_reset();
    // watchdog change enable
    WDTCSR |= (1 << WDCE) | (1 << WDE);
    // enable interrupt, disable system reset, bark every 8 seconds
    WDTCSR = (1 << WDIE) | (0 << WDE) | (1 << WDP3) | (1 << WDP0);
}

/**
 * Sets up the ADC.
 */
static void initADC(void) {
    // disable digital input on the ADC inputs to reduce digital noise
    DIDR0 = 0b00111111;
    // ADC clock prescaler/64 ~ 125kHz @ 8MHz
    ADCSRA |= (1 << ADPS2) | (1 << ADPS1);
    // enable ADC interrupt
    ADCSRA |= (1 << ADIE);
}

/**
 * Powers on the sensors.
 */
static void powerOnSensors(void) {
    PORT_SENS |= (1 << PIN_PWR);
}

/**
 * Powers off the sensors.
 */
static void powerOffSensors(void) {
    PORT_SENS &= ~(1 << PIN_PWR);
}

/**
 * Enables the ADC.
 */
static void enableADC(void) {
    ADCSRA |= (1 << ADEN);
}

/**
 * Disables the ADC.
 */
static void disableADC(void) {
    ADCSRA &= ~(1 << ADEN);
}

/**
 * Enables SPI.
 */
static void enableSPI(void) {
    SPCR |= (1 << SPE);
}

/**
 * Disables SPI.
 */
static void disableSPI(void) {
    SPCR &= ~(1 << SPE);
    PORT_SPI &= ~(1 << PIN_SCK);
}

/**
 * Stops the clock of unused modules to reduce power consumption.
 */
static void reducePower(void) {
    // stop TWI, Timer0, Timer1, Timer2 and USART
    PRR |= (1 << PRTWI) | (1 << PRTIM0) | (1 << PRTIM1) | (1 << PRTIM2) | (1 << PRUSART0);
}

/**
 * Disables global interrupts and the watchdog to stop measuring 
 * and updating the display when batteries are too weak, to limit 
 * discharging below cutoff voltage.
 */
static void powerDown(void) {
    cli();
    wdt_disable();
}

int main(void) {

    reducePower();
    initPins();
    initSPI();
    initWatchdog();
    initADC();
    // initUSART();

    // enable global interrupts
    sei();
    
    // delay initial display update after power on
    _delay_ms(1000);

    while (true) {
        if (ints % MEASURE_INTS == 0) {
            powerOnSensors();
            // give the humidity sensor time to settle
            _delay_ms(100);
            enableADC();
            measureValues();
            disableADC();
            powerOffSensors();

            if (ints >= DISP_UPD_INTS) {
                ints = 0;

                // measured battery voltage is /5 by voltage divider
                if (getMVBat() < BAT_LOW / 5) {
                    powerDown();
                } else {
                    enableSPI();
                    if (updates > DISP_MAX_FAST) {
                        // make a full update after a certain number of fast 
                        // updates to avoid ghosting
                        displayValues(false);
                        updates = 0;
                    } else {
                        if (displayValues(true)) {
                            updates++;
                        }
                    }
                    disableSPI();
                }
            }
        }

        set_sleep_mode(SLEEP_MODE_PWR_DOWN);
        sleep_mode();
    }

    return 0;
}

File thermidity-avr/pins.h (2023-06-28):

/* 
 * File:   pins.h
 * Author: torsten.roemer@luniks.net
 *
 * Created on 1. April 2023, 19:25
 */

#ifndef PINS_H
#define PINS_H

#include <avr/io.h>

/* Sensors */
#define DDR_SENS  DDRC
#define PORT_SENS PORTC
#define PIN_PWR   PC1
#define PIN_TMP   PC2
#define PIN_RH    PC3
#define PIN_BAT   PC0

/* SPI */
#define DDR_SPI   DDRB
#define PORT_SPI  PORTB
#define PIN_SS    PB2
#define PIN_MOSI  PB3
#define PIN_MISO  PB4
#define PIN_SCK   PB5

/* SRAM */
#define DDR_SSPI  DDRD
#define PORT_SSPI PORTD
#define PIN_SRCS  PD7 // SRAM chip select

/* Display */
#define DDR_DSPI  DDRB
#define PORT_DSPI PORTB
#define PIN_ECS   PB1 // display chip select
#define PIN_DC    PB0 // display data/command

#define DDR_DISP  DDRD
#define PORT_DISP PORTD
#define PINP_DISP PIND
#define PIN_RST   PD6 // display reset
#define PIN_BUSY  PD5 // display busy

#endif /* PINS_H */

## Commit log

2023-05-09 change and fix intervals of measuring and displaying values
    [thermidity.c]
2023-05-17 use 3.0V voltage reference for AREF, measure battery voltage (#6)
2023-05-17 use 3.0V voltage reference for AREF, measure battery voltage
2023-05-18 display a battery level symbol (#8)
2023-05-18 save power with watchdog: reduces from 7 to 1.1 mA, but still too much (#9)
    - use watchdog to wake up the controller every 8 seconds
    - set to power save mode
    - use ADC noise reduction mode for conversion
    [thermidity.c]
2023-05-19 stop the clock of unused modules to reduce power consumption
2023-05-21 add FreeCAD subproject for frame
    [Thermidity.FCStd, Thermidity.step]
2023-05-21 add initial schematic
    [thermidity.kicad_pcb, thermidity.kicad_sch]
2023-05-21 move KiCad project
    [thermidity.kicad_pcb, thermidity.kicad_sch]
2023-05-22 remove 100nF cap from humidity sensor
    [thermidity.kicad_sch]
2023-05-23 update schematic
    [thermidity.kicad_sch]
2023-05-23 use timer2 to wake up from power save mode (#11)
    - seems to consume less power than using watchdog
    - allows to be clocked by external watch crystal and use even less power
2023-05-25 Power save mode with asynchronous timer2 clocked from external 32kHz watch crystal (#12)
    * use timer2 with external crystal - 0.6 mA, already quite good
    * disable ADC before going to sleep - saves another 200 uA
    * update README, add crystal to schematic
    [thermidity.kicad_sch]
2023-05-29 improve circuit, update schematic, initial PCB, adjust pins
    [thermidity.kicad_pcb, thermidity.kicad_sch]
2023-05-31 Use watchdog to wake up MCU from sleep mode every second (#13)
    - avoids increasing current draw with 8 second interval
    - remove unnecessary checks
    - giving the ADC some time after sleep mode is not necessary
    [pins.h, thermidity.c]
2023-05-31 minor schematic layout changes
    [thermidity.kicad_sch]
2023-06-01 try to save some more power
    - use power-down sleep mode
    - stop timer2 clock as well
2023-06-01 update README, schematic + PCB (remove crystal)
    [thermidity.kicad_pcb, thermidity.kicad_sch]
2023-06-02 improve PCB, add comments
    [thermidity.kicad_pcb, thermidity.kicad_sch]
2023-06-04 improve PCB
    [thermidity.kicad_pcb, thermidity.kicad_sch]
2023-06-04 trying to finalize...
    [thermidity.kicad_pcb]
2023-06-06 put back ground area and add vias for better connection
    [thermidity.kicad_pcb]
2023-06-06 use print instead of SMD for JST connector
    [thermidity.kicad_pcb, thermidity.kicad_sch]
2023-06-07 power off vref during idle time reducing consumption from 400uA to 43uA
    - power off vref including humidity sensor
    - add serial resistor to reduce charge current
    - fix pin initialization
    [thermidity.kicad_pcb, thermidity.kicad_sch]
2023-06-09 correct handling of variables > 8 bit shared between ISR and main execution path
    [thermidity.c]
2023-06-11 ratiometric measurement of humidity (#16)
    - removed voltage refererence
    - TMP36 to be replaced by thermistor (currently dependent on battery voltage)
    - battery voltage measurement should use internal 1.1 Vref (does not need to be accurate)
    - update schematic and README
    - update PCB
    - measure battery voltage using internal 1.1V reference
    - lower "low battery" limit to 3V which is the minimum for the display
    [thermidity.kicad_pcb, thermidity.kicad_sch]
2023-06-11 remove the 1pF capacitor between AREF and GND
    - takes ~125us to discharge after switching from AVCC to internal 1.1 voltage reference and for the reference to settle
    - shouldn't be necessary and hopefully the 16x oversampling benefits from some noise
    - one part less
    [thermidity.kicad_pcb, thermidity.kicad_sch]
2023-06-13 Ratiometric measurement of temperature with a thermistor (#18)
    - replace TMP36 with a thermistor NTC 100k
    - put back 1nF cap between AREF and GND
    - wait 150us for the cap to discharge before converting with 1.1V reference
    - uint16_t is enough for 16x ADC
    - SMD footprint instead of TH for thermistor
    - calculate temperature
    - rounding of temperature compensated relative humidity
    - no need for battery voltage in mV
    [thermidity.kicad_pcb, thermidity.kicad_sch]
2023-06-15 update README and schematic + PCB
    [thermidity.kicad_pcb, thermidity.kicad_sch]
2023-06-15 adjust battery levels
    - display needs at least 3+V, so show empty below 3.2V
    - remove unused constant
2023-06-16 measured power consumption with a supercap capacitor
2023-06-20 fine tuning
    - measure every 32 seconds (save power)
    - update display every 288 seconds (save power)
    - lower weight of the moving average (less inert)
    - set display to deep sleep mode 2 (save power)
2023-06-23 more infos about power consumption
2023-06-28 optimizations on battery usage (#21)
    - more fine grained display of display voltage
    - try to avoid discharging batteries below cutoff voltage
    [meter.h, pins.h, thermidity.c]
2023-07-02 pull not drive (input pin)
2023-07-03 add fast update mode, refactor and simplify (#22)
    - includes BOM
    [thermidity.csv]
2023-07-30 disable SPI between display updates, fix schematic (#24)
    - fix high power consumption of display in sleep mode by disabling SPI (driving SCK low)
    - remove "unconnected" from MCU pin 20 (AREF) as it is connected
    - update README and manual
    [thermidity.kicad_pcb, thermidity.kicad_sch]
2023-07-30 disable SPI between display updates, fix schematic
    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
2023-07-30 add ISP header pin layout to manual
2023-08-04 keep ground plane away from mounting holes (#25)
    [thermidity.kicad_pcb]
2023-08-09 add drillholes to frame (#27)
    [Thermidity-BodySketch.step, Thermidity.FCStd, Thermidity.step]
2023-09-09 remove unnecessary delays in display initialization (#36)
    - no need to wait 10ms since VCI already supplied, display is in deep sleep mode
    - no need to wait 100ms after hardware eset (waiting for busy) before software reset
    => might contribute to a tiny reduction of power consumption
2023-09-14 Let watchdog wake up MCU only every 8 instead of 1 seconds, saving some power (#38)
    - set watchdog to bark every 8 seconds
    - counter can now be 8 instead of 16 bit - ATOMIC_BLOCK not needed
    - adjust constant and variable names
    - saves about 4uA in average power consumption
2023-09-17 More optimizations (#39)
    * use 'typedef uint8_t code_t' for char codes instead of uint16_t
    * use 'typedef uint8_t height_t' for bitmap height instead of uint16_t, same for width, row, col
    * optimize writing strings to and reading strings from SRAM (not used)
    * delay initial display update after power on (not necessary but avoids two consecutive display updates when connecting the programmer (display update starts almost immediately after power on and restarts when programmer resets after ~1 second))
    [thermidity.c]
2023-09-20 set frame in SRAM sequential mode, saving more power (#43)
2023-10-08 add STEP for whole frame, update PDF (#46)
    [Thermidity-Body.step]
2023-10-09 update to KiCad 7.0, add PDF for schematic and PCB (#47)
    [thermidity.kicad_pcb, thermidity.kicad_sch]

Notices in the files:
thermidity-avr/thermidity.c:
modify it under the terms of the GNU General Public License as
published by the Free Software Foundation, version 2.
